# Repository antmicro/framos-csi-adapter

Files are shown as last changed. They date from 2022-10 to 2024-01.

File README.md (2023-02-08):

# Framos CSI Adapter

Copyright (c) 2022 [Antmicro](https://www.antmicro.com>)

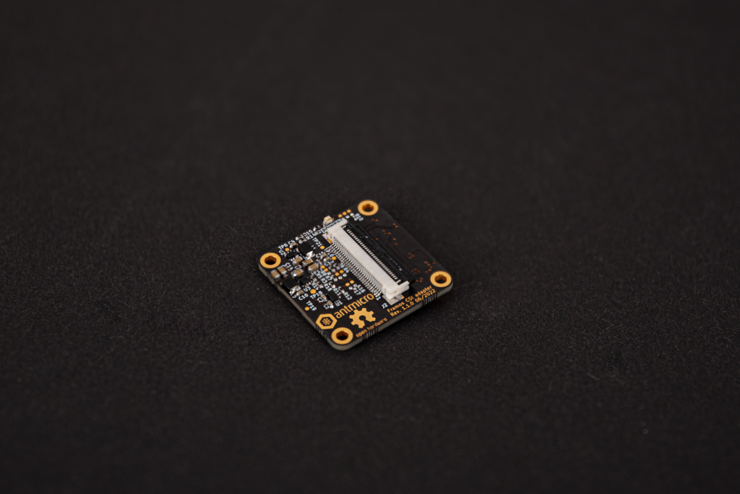
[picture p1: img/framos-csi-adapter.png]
FSA to CSI Adapter


## Overview

This repository contains open hardware design files for an FSA to CSI Adapter.

The board serves as a connector adapter between a [FRAMOS Sensor Module Adapter](https://www.framos.com/en/products/framos-sensor-module-adapter-fsa-22408) (FSA) and a 30-wire I-PEX micro coax cable.

The adapter board is the same size as the FSA and can be stacked with it.
The adapter board can be interfaced with a variety of video processing platforms created by Antmicro using the [Dual I-PEX CSI Interposer](https://github.com/antmicro/dual-ipex-csi-interposer).

## Repository structure

The main repository directory contains KiCad PCB project files, a [LICENSE](LICENSE), and a README.

The remaining files are stored in the following directories:

* `lib` - contains the component libraries
* `doc` - contains the adapter [schematics](doc/framos-csi-adapter.pdf)
* `img` - contains graphics for this README

## Key features

* MIPI CSI-2 camera interface
* On-board DC-DC converters to power the FSA board and camera module
* I2C bus voltage level translator
* DF40C-60DS connector for [FRAMOS Sensor Module Adapter](https://www.framos.com/en/products/framos-sensor-module-adapter-fsa-22408)
* MSAK24024 Series 30-pin IPEX-type connector

## License

[Apache-2.0](LICENSE)

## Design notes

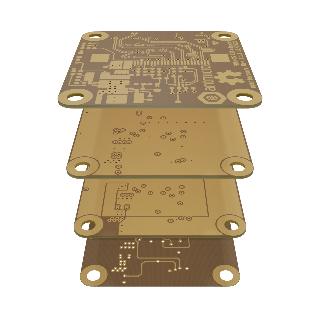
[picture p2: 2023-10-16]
assets/previews/layer1_thumbnail.webp

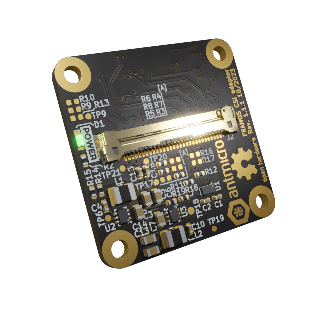
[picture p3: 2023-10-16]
assets/previews/leftT_thumbnail.png

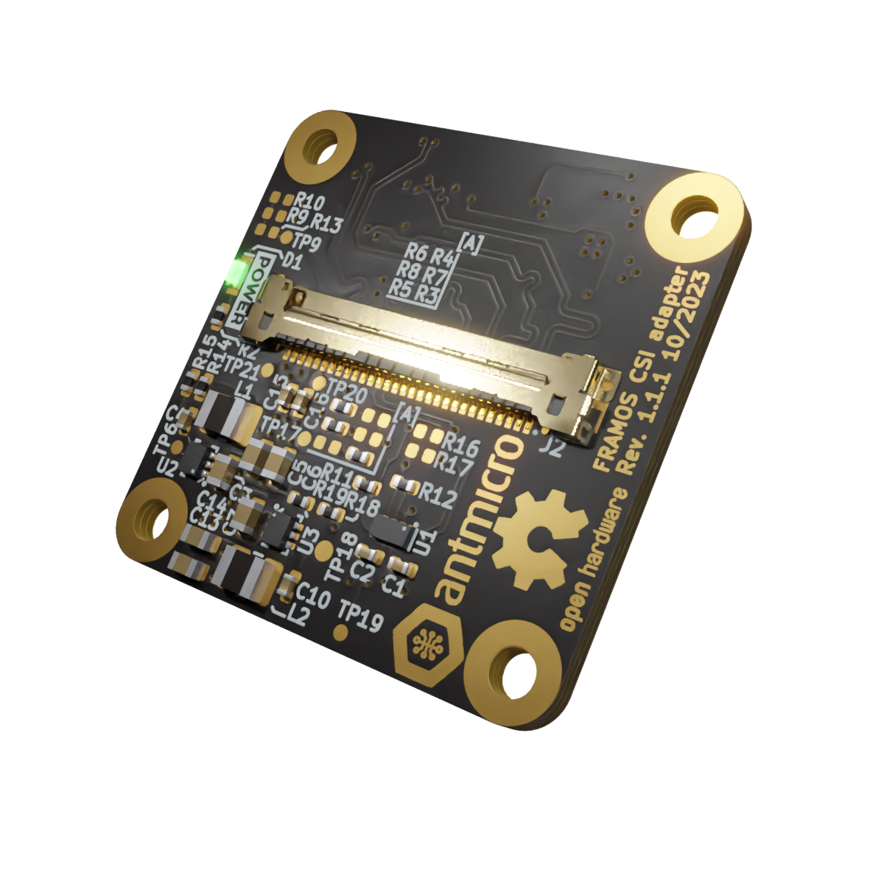
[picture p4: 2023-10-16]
assets/previews/rightT.webp

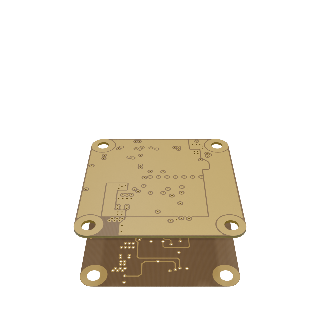
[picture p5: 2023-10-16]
assets/previews/layer3_thumbnail.webp

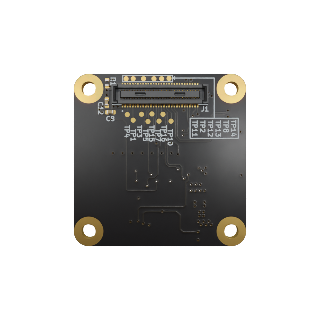
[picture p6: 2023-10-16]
assets/previews/orthoB_thumbnail.webp

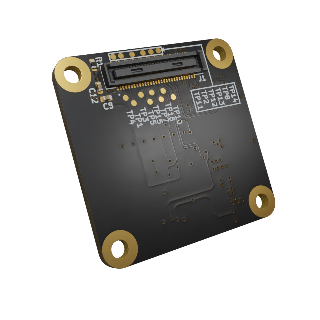
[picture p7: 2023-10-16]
assets/previews/leftB_thumbnail.png

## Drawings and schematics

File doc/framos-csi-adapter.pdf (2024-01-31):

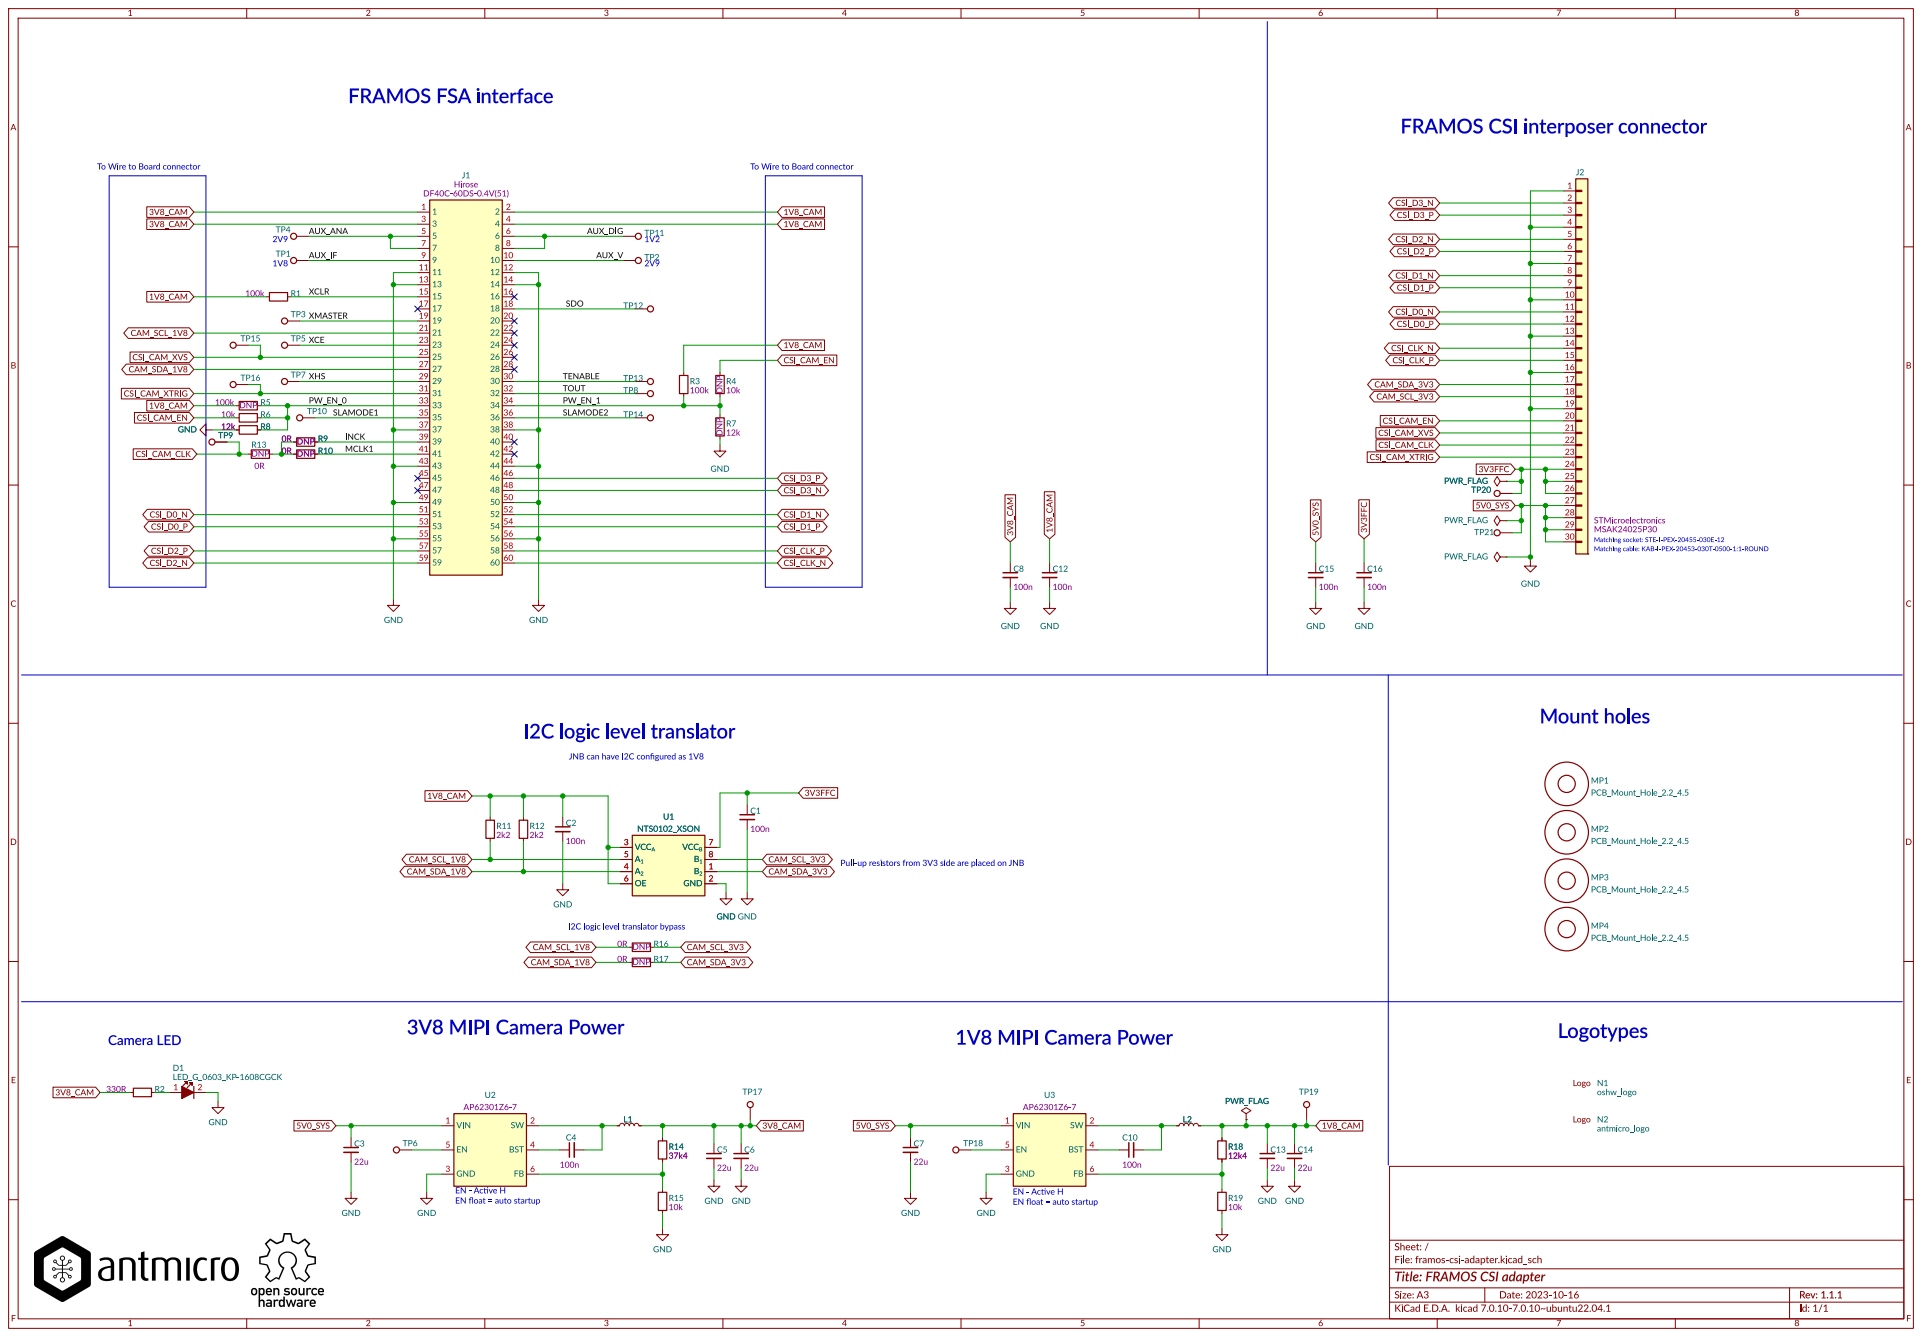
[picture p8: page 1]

I2C logic level translator bypass

EN float = auto startup 3V8 MIPI CameraPower

EN - Active H
EN float = auto startup

Id: 1/1 Title:FRAMOSCSIadapter File: framos-csi-adapter.kicad_sch Sheet:/

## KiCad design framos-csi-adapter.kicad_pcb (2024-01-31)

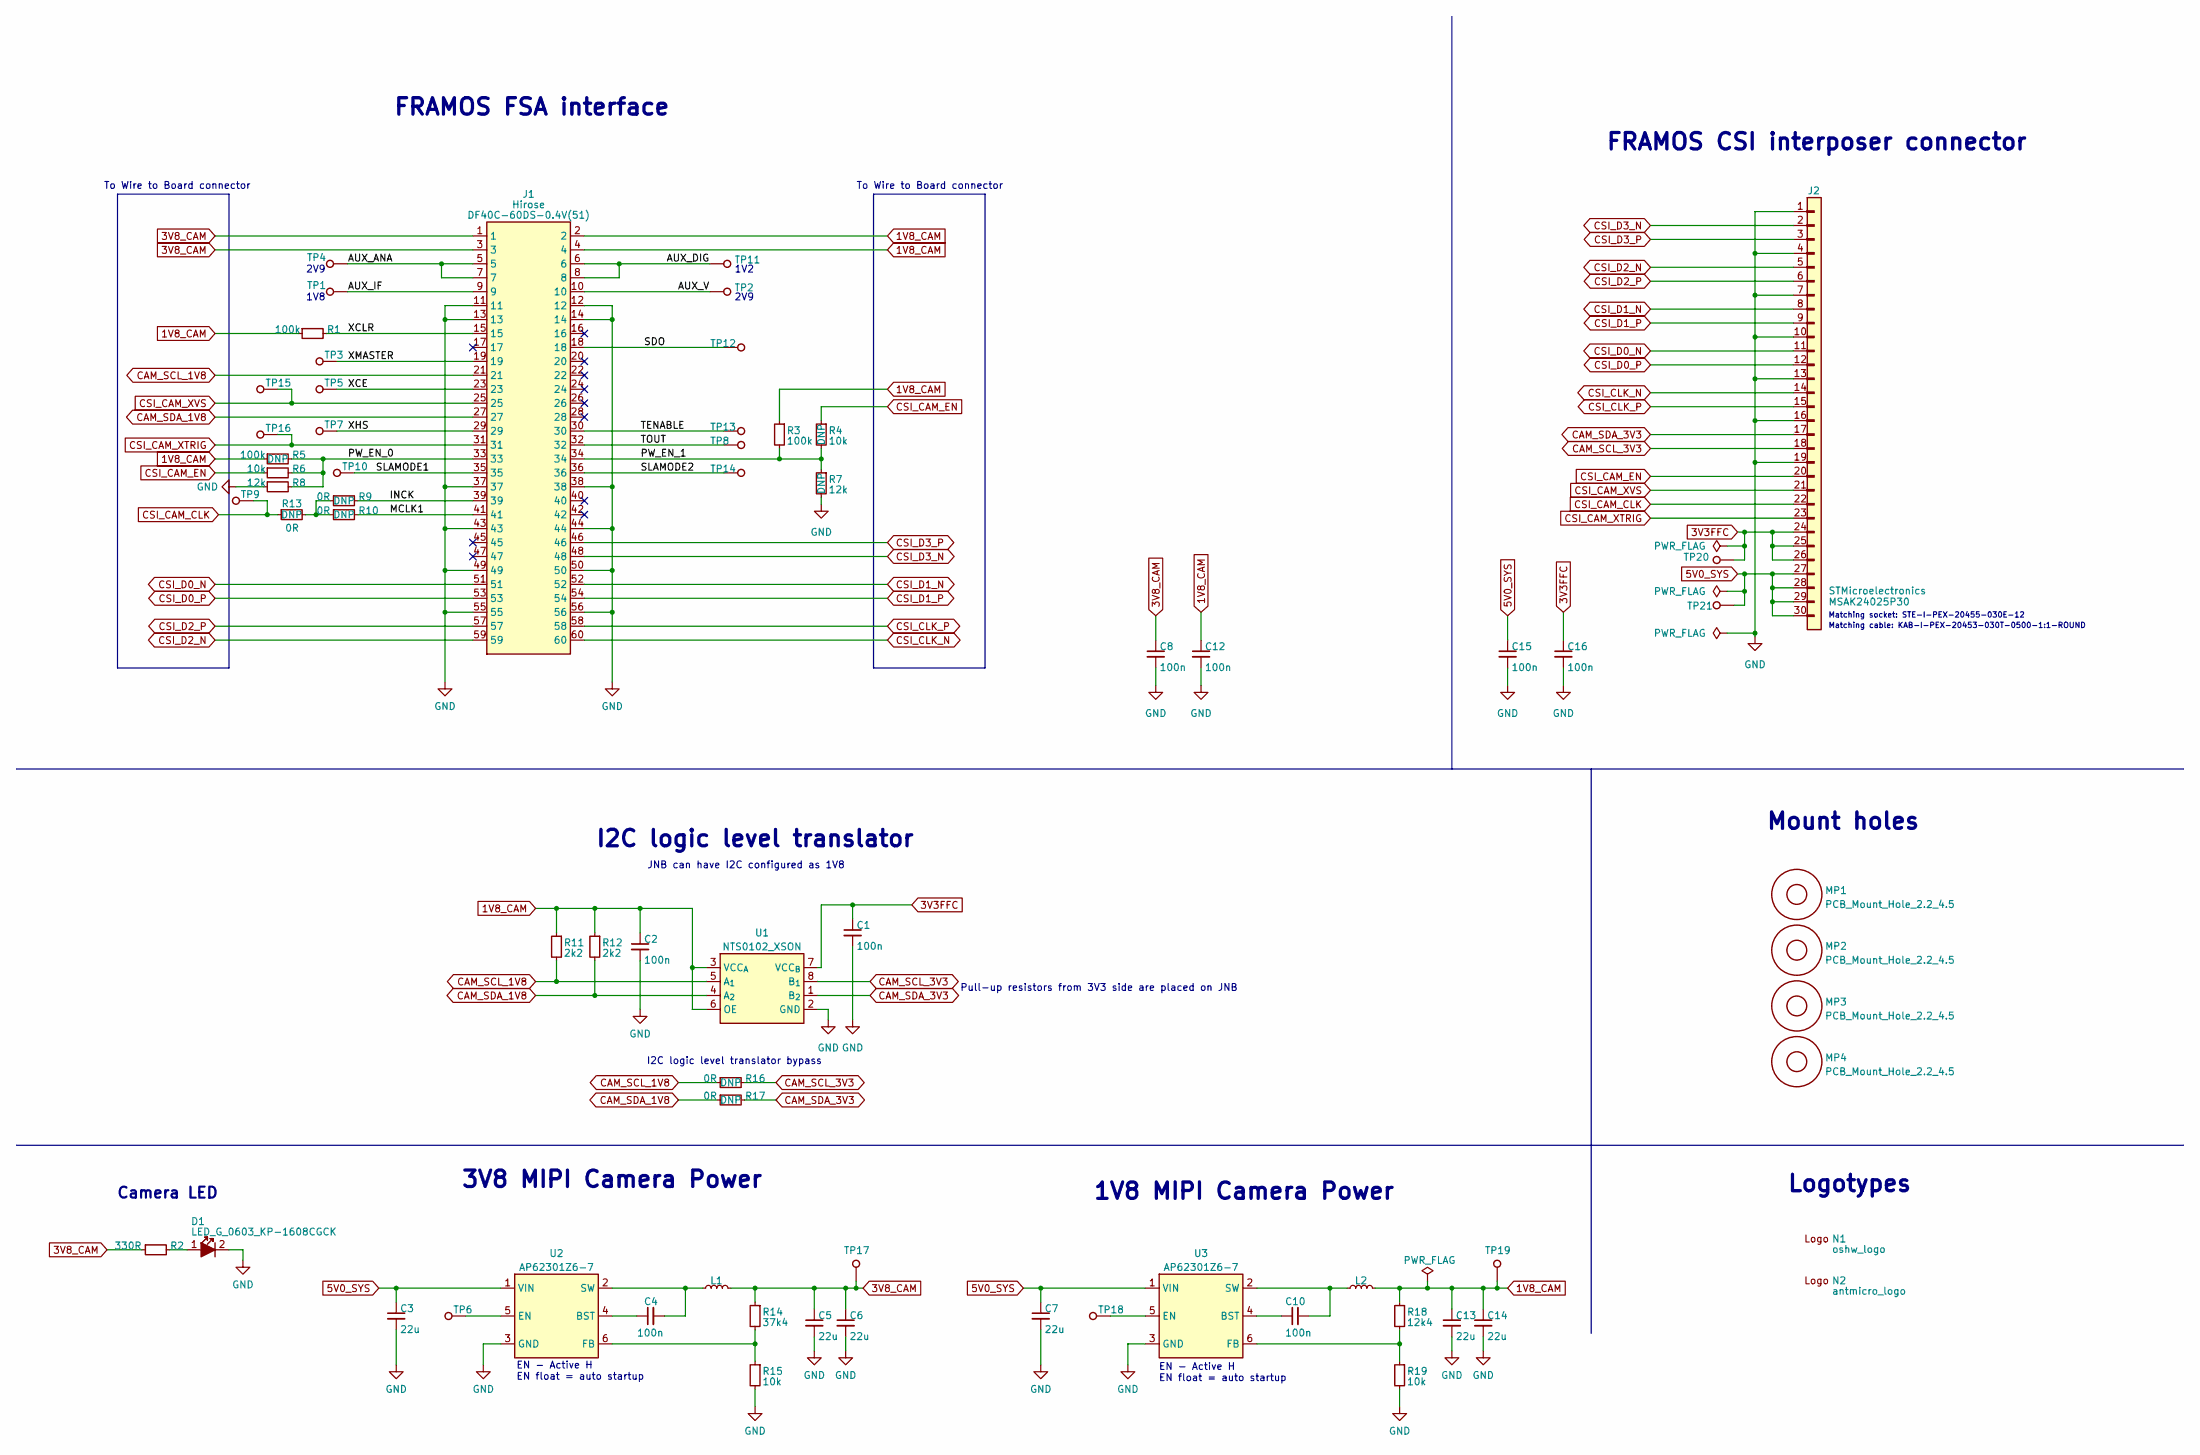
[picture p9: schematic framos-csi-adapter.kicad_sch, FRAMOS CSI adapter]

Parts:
C1, C2, C4, C8, C10, C12, C15, C16: C_100n_0402; C_0402_1005Metric; Voltage 50V; MPN GRM155R61H104KE14D
C3, C5, C6, C7, C13, C14: C_22u_0603; C_0603_1608Metric; MPN GRM188R60J226MEA0D
D1: LED_G_0603_KP-1608CGCK; LED_0603_1608Metric_G; MPN KP-1608CGCK
J1: Conn_Hirose_DF40C-60DS-0.4V51; MPN DF40C-60DS-0.4V(51)
J2: Conn_STM_MSAK24025P30; MPN MSAK24025P30
L1, L2: 74479887222C; L_1008_2520Metric; MPN 74479887222C
MP1, MP2, MP3, MP4: PCB_Mount_Hole_2.2_4.5; mounting-hole-2.2mm
N1: oshw_logo; OSHW-Logo2_7.3x6mm_Copper_Mask
N2: antmicro_logo; antmicro-logo_scaled_12mm
R1, R3, R5: R_100k_0402; R_0402_1005Metric; Tolerance 1%; MPN CR0402-FX-1003GLF
R2: R_330R_0402; R_0402_1005Metric; Tolerance 1%; MPN CR0402-FX-3300GLF
R4, R6, R15, R19: R_10k_0402; R_0402_1005Metric; Tolerance 1%; MPN CR0402-FX-1002GLF
R7, R8: R_12k_0402; R_0402_1005Metric; Tolerance 1%; MPN CR0402-FX-1202GLF
R9, R10, R13, R16, R17: R_0R_0402; R_0402_1005Metric; MPN ERJ2GE0R00X
R11, R12: R_2k2_0402; R_0402_1005Metric; Tolerance 1%; MPN CR0402-FX-2201GLF
R14: R_37k4_0402; R_0402_1005Metric; Tolerance 1%; MPN CR0402-FX-3742GLF
R18: R_12k4_0402; R_0402_1005Metric; Tolerance 1%; MPN CR0402-FX-1242GLF
TP1, TP2, TP3, TP4, TP5, TP6, TP7, TP8, TP9, TP10, TP11, TP12, TP13, TP14, TP15, TP16, TP17, TP19, TP20, TP21: TP_0.75mm_SMD; TP_SMD_0.75mm
TP18: TP_1mm_SMD; Testpoint_smd_1mm
U1: NTS0102_XSON; XSON-8_1x1.95mm_P0.5mm; MPN NTS0102GT
U2, U3: AP62301Z6-7; SOT-563; MPN AP62301Z6-7

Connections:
1V8_CAM: C2.1, C12.1, C13.1, C14.1, J1.2, J1.4, L2.2, R1.1, R3.1, R5.1, R11.1, R12.1, R18.1, TP19.1, U1.3 (VCC_{A}), U1.6 (OE)
3V3FFC: C1.1, C16.1, J2.24, J2.25, J2.26, TP20.1, U1.7 (VCC_{B})
3V8_CAM: C5.1, C6.1, C8.1, J1.1, J1.3, L1.2, R2.1, R14.1, TP17.1
5V0_SYS: C3.1, C7.1, C15.1, J2.27, J2.28, J2.29, J2.30, TP21.1, U2.1 (VIN), U3.1 (VIN)
/AUX_ANA: J1.5, J1.7, TP4.1
/AUX_DIG: J1.6, J1.8, TP11.1
/AUX_IF: J1.9, TP1.1
/AUX_V: J1.10, TP2.1
/INCK: J1.39, R9.2
/MCLK1: J1.41, R10.2
/PW_EN_0: J1.33, R5.2, R6.2, R8.2
/PW_EN_1: J1.34, R3.2, R4.2, R7.1
/SDO: J1.18, TP12.1
/SLAMODE1: J1.35, TP10.1
/SLAMODE2: J1.36, TP14.1
/TENABLE: J1.30, TP13.1
/TOUT: J1.32, TP8.1
/XCE: J1.23, TP5.1
/XCLR: J1.15, R1.2
/XHS: J1.29, TP7.1
/XMASTER: J1.19, TP3.1
CAM_SCL_1V8: J1.21, R11.2, R16.1, U1.5 (A_{1})
CAM_SCL_3V3: J2.18, R16.2, U1.8 (B_{1})
CAM_SDA_1V8: J1.27, R12.2, R17.1, U1.4 (A_{2})
CAM_SDA_3V3: J2.17, R17.2, U1.1 (B_{2})
CSI_CAM_CLK: J2.22, R13.1, TP9.1
CSI_CAM_EN: J2.20, R4.1, R6.1
CSI_CAM_XTRIG: J1.31, J2.23, TP16.1
CSI_CAM_XVS: J1.25, J2.21, TP15.1
CSI_CLK_N: J1.60, J2.14
CSI_CLK_P: J1.58, J2.15
CSI_D0_N: J1.51, J2.11
CSI_D0_P: J1.53, J2.12
CSI_D1_N: J1.52, J2.8
CSI_D1_P: J1.54, J2.9
CSI_D2_N: J1.59, J2.5
CSI_D2_P: J1.57, J2.6
CSI_D3_N: J1.48, J2.2
CSI_D3_P: J1.46, J2.3
GND: C1.2, C2.2, C3.2, C5.2, C6.2, C7.2, C8.2, C12.2, C13.2, C14.2, C15.2, C16.2, D1.2, J1.11, J1.12, J1.13, J1.14, J1.37, J1.38, J1.43, J1.44, J1.49, J1.50, J1.55, J1.56, J2.1, J2.4, J2.7, J2.10, J2.13, J2.16, J2.19, R7.2, R8.1, R15.2, R19.2, U1.2 (GND), U2.3 (GND), U3.3 (GND)
unnamed: D1.1, R2.2
unnamed: R9.1, R10.1, R13.2
unnamed: C4.1, U2.4 (BST)
unnamed: TP6.1, U2.5 (EN)
unnamed: R14.2, R15.1, U2.6 (FB)
unnamed: C4.2, L1.1, U2.2 (SW)
unnamed: C10.1, U3.4 (BST)
unnamed: TP18.1, U3.5 (EN)
unnamed: R18.2, R19.1, U3.6 (FB)
unnamed: C10.2, L2.1, U3.2 (SW)

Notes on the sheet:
To Wire to Board connector
EN - Active H EN float = auto startup
FRAMOS FSA interface
1V8 MIPI Camera Power
1V8
Logotypes
Matching cable: KAB-I-PEX-20453-030T-0500-1:1-ROUND
JNB can have I2C configured as 1V8
Mount holes
Pull-up resistors from 3V3 side are placed on JNB
FRAMOS CSI interposer connector
I2C logic level translator
1V2
2V9
Matching socket: STE-I-PEX-20455-030E-12
Camera LED
I2C logic level translator bypass
3V8 MIPI Camera Power

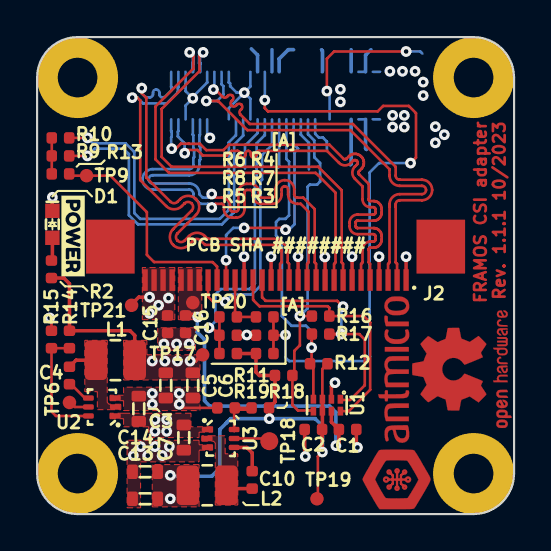
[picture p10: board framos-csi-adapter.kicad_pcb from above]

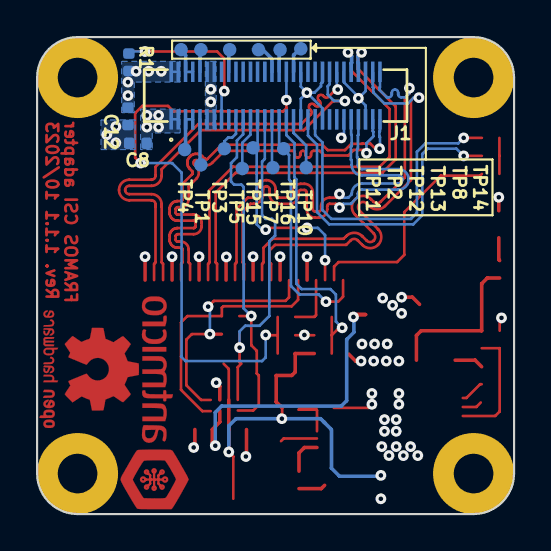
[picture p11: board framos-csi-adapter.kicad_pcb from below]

Board: 4 copper layers, 26.5 x 26.5 mm, 69 parts (22 on the bottom side), 50 nets.

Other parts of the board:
kibuzzard-621A77E1: G***; label

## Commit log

2022-01-21 Initial commit - Add PCB design
    [framos-csi-adapter.kicad_pcb, framos-csi-adapter.sch]
2022-01-21 Move R1 to top
    [framos-csi-adapter.kicad_pcb]
2022-02-14 Add 3V8 and 1V8 DC/DC to the schematic
    [framos-csi-adapter.sch]
2022-02-21 Add 4-line CSI support - update pinout
    [framos-csi-adapter.sch]
2022-02-25 Move power supply sections on PCB
    [framos-csi-adapter.kicad_pcb, framos-csi-adapter.sch]
2022-02-27 Tweak FB resistors, change L1 and L2 to smaller size
    [framos-csi-adapter.sch]
2022-07-28 Update DF40C-60DS-0.4V51 footprint
2022-07-28 Layout, tunning
    [framos-csi-adapter.kicad_pcb]
2022-07-28 Changed voltage translator to XSON8 package. Crossed P and N signals on D2 and D3 lanes
    [framos-csi-adapter.kicad_pcb, framos-csi-adapter.sch]
2022-07-28 Fixed diff traces impedance
    [framos-csi-adapter.kicad_pcb, framos-csi-adapter.kicad_sch]
2022-07-28 Added TP silkscreen map
    [framos-csi-adapter.kicad_pcb]
2022-07-28 Adjust position of passives around U1
    [framos-csi-adapter.kicad_pcb]
2022-07-28 Adjust position of the bottom TP labels
    [framos-csi-adapter.kicad_pcb]
2022-07-28 Bump revision to 1.1.0
    [framos-csi-adapter.kicad_pcb, framos-csi-adapter.kicad_sch]
2022-07-28 Revert PN to DF40C-60DS-0.4V(51)
    [framos-csi-adapter.kicad_sch]
2022-07-28 Migrate to KiCad 6. Add LICENSE and README. Correct OSHW logo footprint
    [framos-csi-adapter.kicad_pcb, framos-csi-adapter.kicad_sch, framos-csi-adapter.sch]
2022-10-13 Add PDF Schematic
2023-10-16 Introduce component standardization
    [framos-csi-adapter.kicad_pcb, framos-csi-adapter.kicad_sch]
2023-10-16 Bump revision date
    [framos-csi-adapter.kicad_sch]
2023-10-16 Add OHP assets
    [stackup.csv]
2024-01-31 [#54543] Migrate project to KiCad7
    [framos-csi-adapter.kicad_pcb, framos-csi-adapter.kicad_sch]
2024-01-31 [#54543] Loclib
    [framos-csi-adapter.kicad_pcb, framos-csi-adapter.kicad_sch]
2024-01-31 [#54543] Update schematic PDF
